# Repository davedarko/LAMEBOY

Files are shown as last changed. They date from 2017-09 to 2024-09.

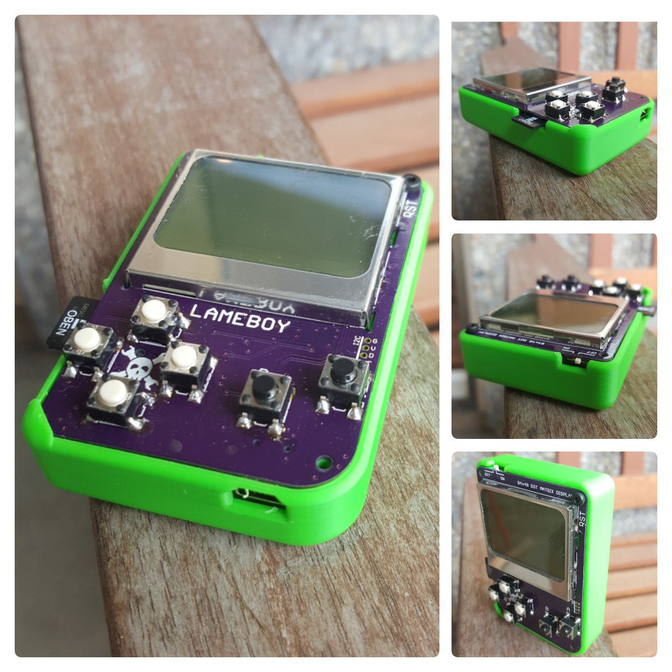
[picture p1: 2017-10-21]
Resources/img/lameboy.jpg

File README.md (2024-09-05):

# LAMEBOY
https://hackaday.io/project/26823-lameboy-another-esp12-handheld

Ever since https://hackaday.io/project/18648-nokia-3310-5110-display-board I've wanted to slap on an ESP module and some buttons to make a nice little portable handheld. Now with some googling and checking out other projects how they get their stuff done and a bit time on hand while on vacation I'm using every spare minute to work on this PCB. There are some minor things I'm not sure about that need testing, but the general concept is clear.

The last version - R 3.2.3 - seems to got lost, it was rebranded to Game Toy and some pinouts were changed to make more sense.

LAMEBOY

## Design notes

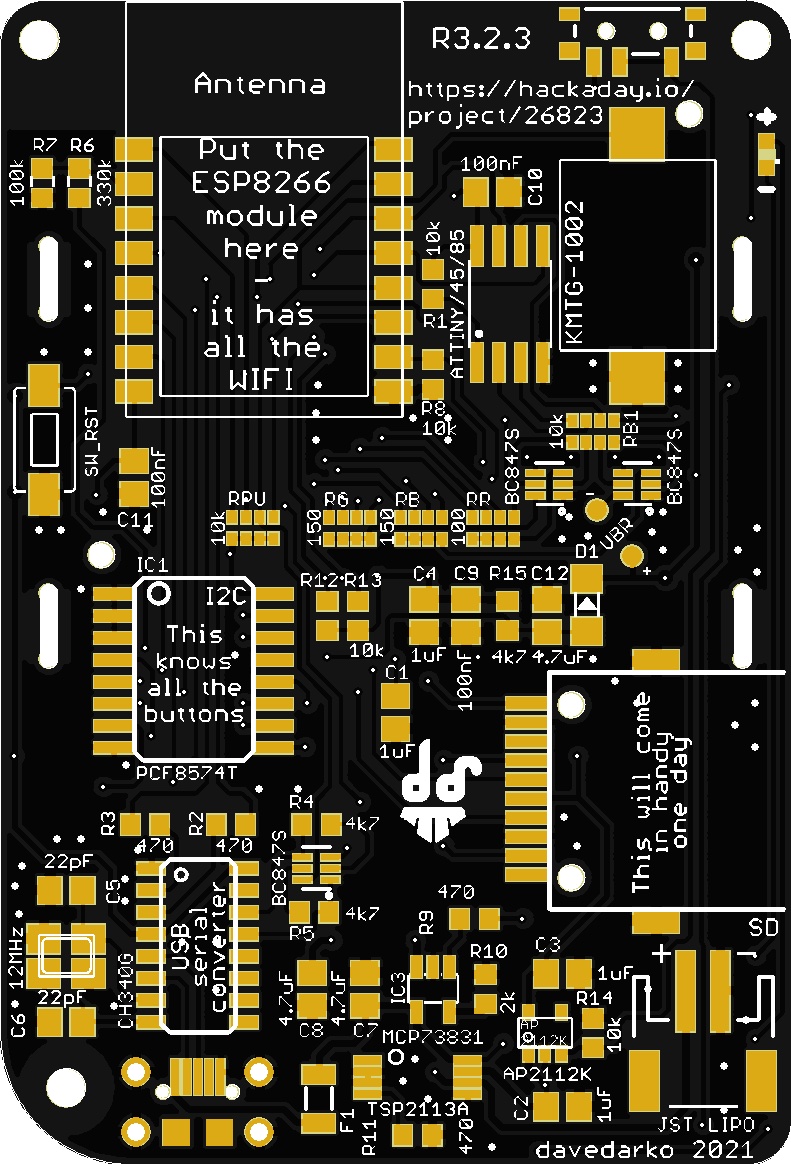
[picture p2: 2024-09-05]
Resources/notBackedUp.jpg

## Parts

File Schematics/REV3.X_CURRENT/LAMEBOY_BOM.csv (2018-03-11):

Qty | Value | Device | Package | Parts | Description | MF | MPN | OC_FARNELL | OC_NEWARK | PROD_ID
1 |  | ESP-12 | ESP-12 | X1
1 |  | JST_2MM_MALE | JST-2-SMD | J1 | Mates to single-cell LiPo batteries. |  |  |  |  | CONN-08352
1 |  | LEDCHARLIE | CHIPLED_0603_CHARLIE | CHARGE | LED
2 |  | SWITCH-MOMENTARY-2-SMD-1101NE | TACTILE-SWITCH-1101NE | SW_C, SW_RST | Various NO switches- pushbuttons, reed, etc
1 | 100 | 4R-N0603-ARC | 0603-ARC | RR | Array Chip Resistor |  |  | unknown | unknown
1 | 100k | R-EU_ONEFITSALL | ONEFITSALL | R7 | RESISTOR, European symbol
3 | 100nF | C-EUONEFITSALL | ONEFITSALL | C9, C10, C11 | CAPACITOR, European symbol
2 | 10k | 4R-N0603-ARC | 0603-ARC | RB1, RPU | Array Chip Resistor |  |  | unknown | unknown
5 | 10k | R-EU_ONEFITSALL | ONEFITSALL | R1, R8, R12, R13, R14 | RESISTOR, European symbol
1 | 12MHz | XTAL-4BIGGER | NX3225_BIGGER | Q1 | Classic 4-pin 3.2 x 2.5mm crystal
2 | 150 | 4R-N0603-ARC | 0603-ARC | RB, RG | Array Chip Resistor |  |  | unknown | unknown
4 | 1uF | C-EUONEFITSALL | ONEFITSALL | C1, C2, C3, C4 | CAPACITOR, European symbol
2 | 22pF | C-EUONEFITSALL | ONEFITSALL | C5, C6 | CAPACITOR, European symbol
1 | 2k | R-EU_ONEFITSALL | ONEFITSALL | R10 | RESISTOR, European symbol
1 | 330k | R-EU_ONEFITSALL | ONEFITSALL | R6 | RESISTOR, European symbol
2 | 4.7uF | C-EUONEFITSALL | ONEFITSALL | C7, C8 | CAPACITOR, European symbol
4 | 470 | R-EU_ONEFITSALL | ONEFITSALL | R2, R3, R9, R11 | RESISTOR, European symbol
2 | 4k7 | R-EU_ONEFITSALL | ONEFITSALL | R4, R5 | RESISTOR, European symbol
1 | AP2112KAP2112K | AP2112KAP2112K | AP2112 | U$9
1 | ATTINY13SO08-WIDE | ATTINY13SO08-WIDE | SO08-EIAJ | U$2 | Atmel 8-pin 1kB flash uC
1 | AVR_SPI_PRG_6 | AVR_SPI_PRG_6 | 2X3_SMD_PAD | JP2 | AVR ISP 6 Pin
3 | BC847S | MMDT3904 | SOT363 | U$3, U$6, U$7 | Dual NPN transistor
1 | CH340GCH340G | CH340GCH340G | SOIC16 | CH340G | USB to TTL RS232 converter
4 | GM1WA55311A | GM1WA55311A | GM1WA55311A | LED1, LED2, LED3, LED4 | Chip LED RGB
1 | I2C_GROVE | I2C_GROVE | I2C_GROVE | U$10
1 | LPH-7366-SLOTS | LPH-7366-SLOTS | LPH-7366-SLOTS | U$1
1 | MCP73831 | MCP73831/OT | SOT23-5L | IC3 | MCP73831/2
1 | PCF8574T | PCF8574T | SO16W | IC1 | I2C-Bus Remote 8-bit I/O expander |  | PCF8574T/3,512 | 1201255 | 70R6870
1 | PTCSMD | PTCSMD | PTC-1206 | F1 | Resettable Fuse PTC |  |  |  |  | RES-11150
1 | PWR | SWITCH-SPDT-SMD-A | SWITCH-SPST-SMD-A | S2 | SPDT Switch
6 | SWITCH-MOMENTARY-2SMD-4 | SWITCH-MOMENTARY-2SMD-4 | TACTILE_SWITCH_TALL | S3, S4, S5, S6, S7, S8 | Various NO switches- pushbuttons, reed, etc |  |  |  |  | SWCH-11966
1 | TPS2113-PW | TPS2113-PW | TEXAS-PW | U$4
1 | USB_MICROB_PLUG-IDK | USB_MICROB_PLUG-IDK | USB-AB-MICRO-SMD_SLOT | JP1 | USB Micro-B connectors
1 | USD-SOCKETMICROSDEBAY | USD-SOCKETMICROSDEBAY | MICRO-SD-SOCKET-EBAY | U1 | microSD Socket

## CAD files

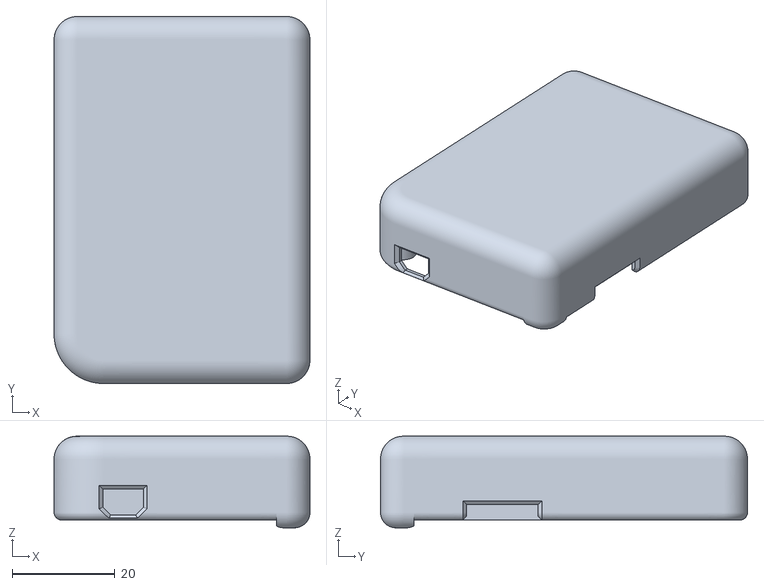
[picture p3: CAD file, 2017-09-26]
CAD/lameboy.stl
49.7 x 71.3 x 17.8

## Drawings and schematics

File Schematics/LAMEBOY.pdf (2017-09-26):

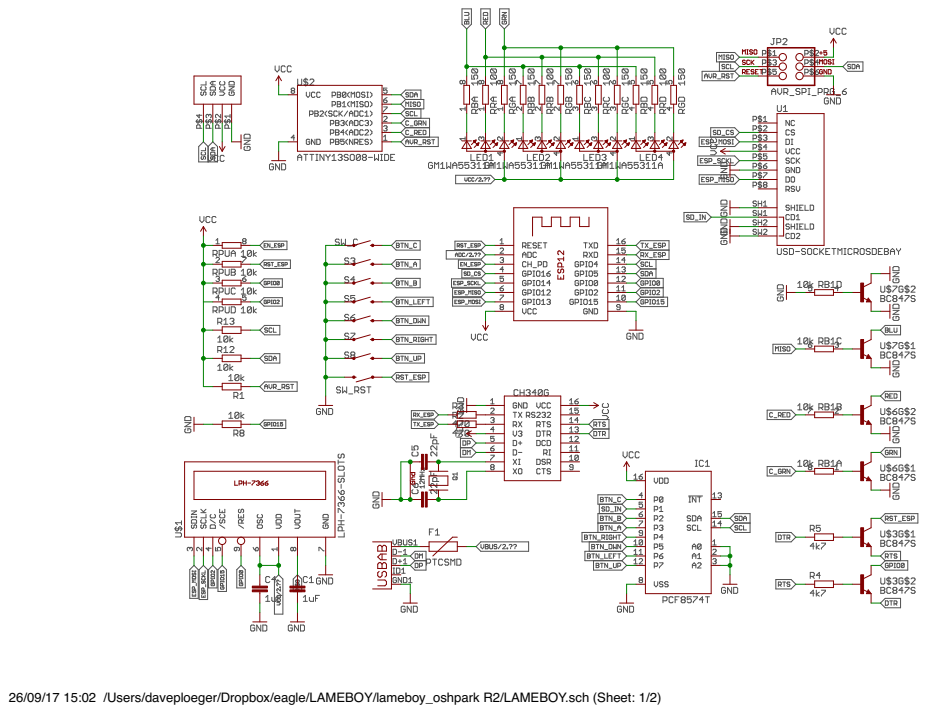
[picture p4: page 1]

26/09/17 15:02 /Users/daveploeger/Dropbox/eagle/LAMEBOY/lameboy_oshpark R2/LAMEBOY.sch (Sheet: 1/2)

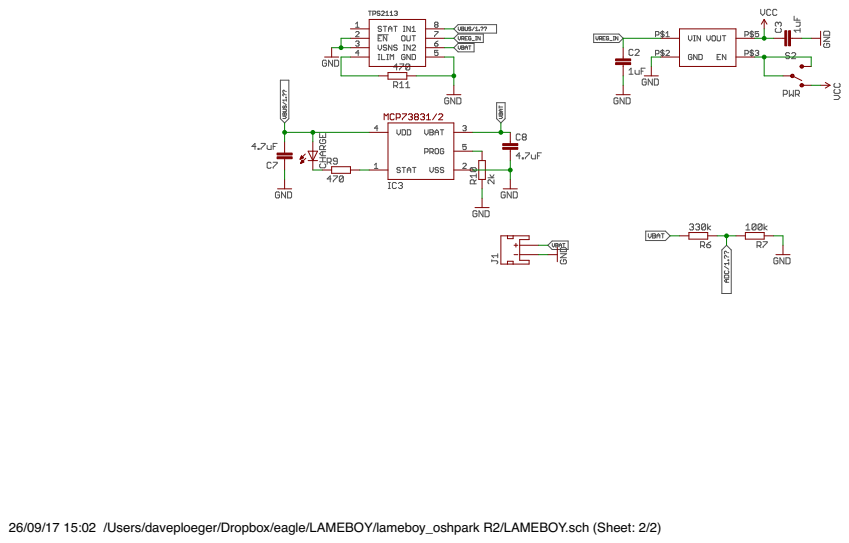
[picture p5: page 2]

26/09/17 15:02 /Users/daveploeger/Dropbox/eagle/LAMEBOY/lameboy_oshpark R2/LAMEBOY.sch (Sheet: 2/2)

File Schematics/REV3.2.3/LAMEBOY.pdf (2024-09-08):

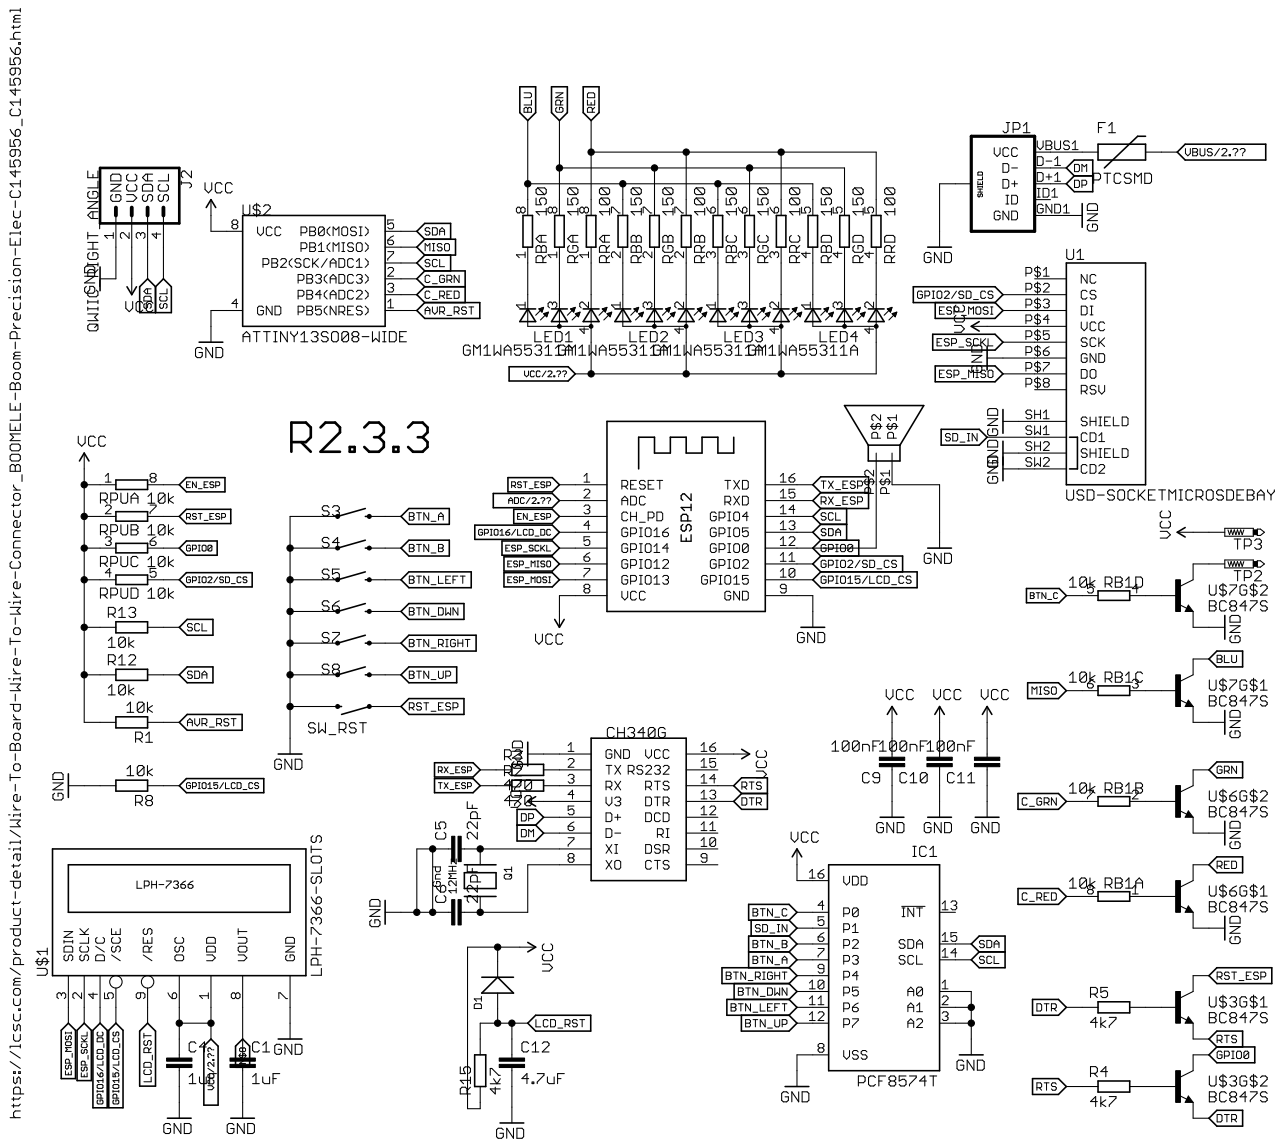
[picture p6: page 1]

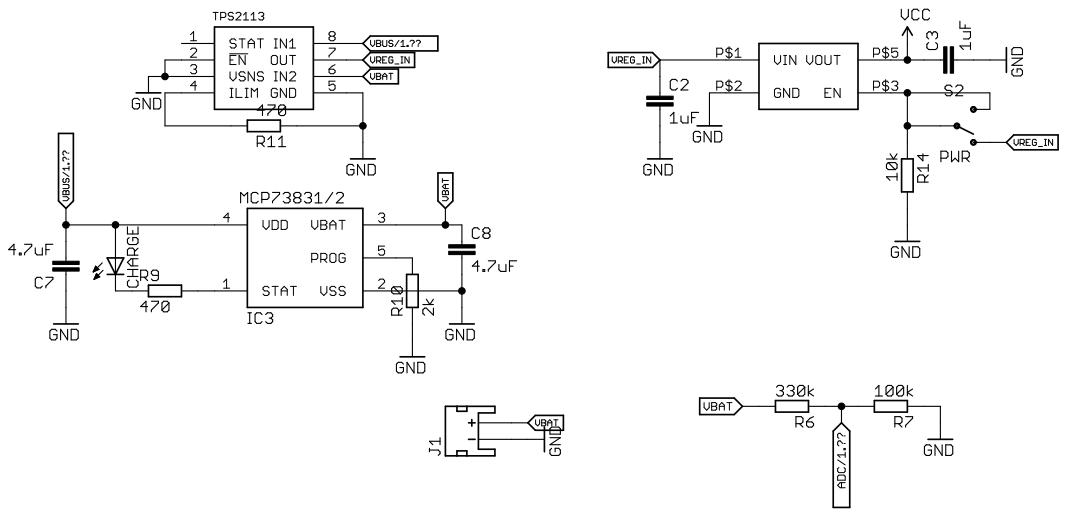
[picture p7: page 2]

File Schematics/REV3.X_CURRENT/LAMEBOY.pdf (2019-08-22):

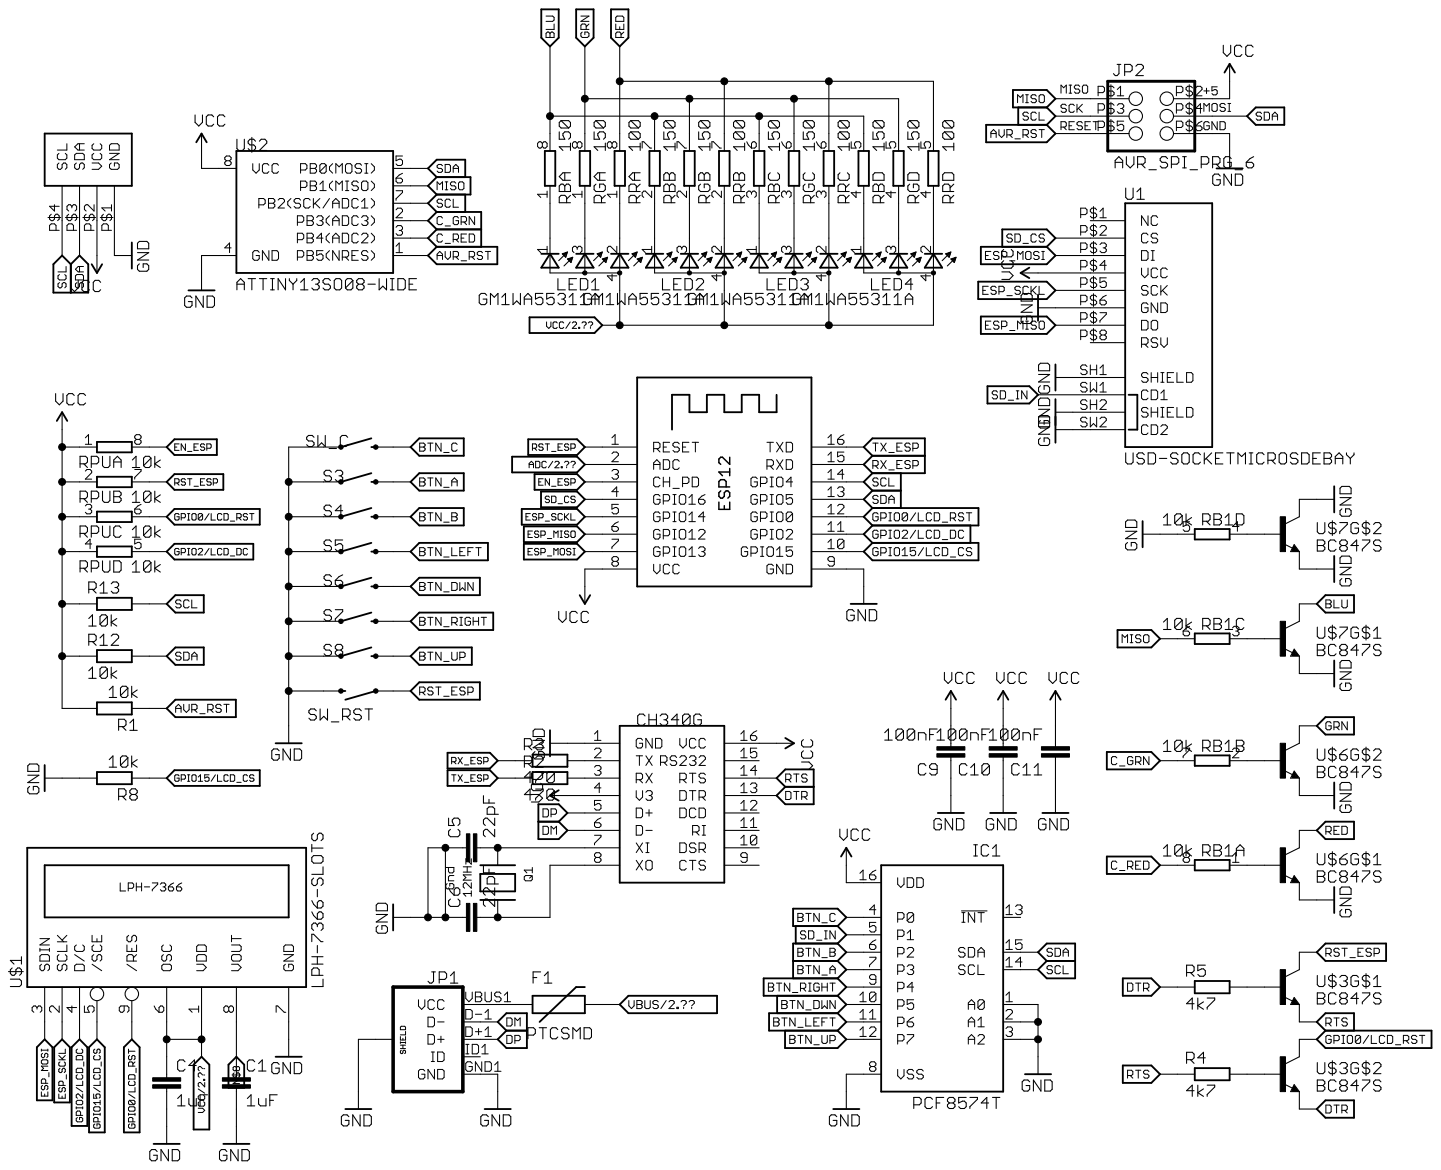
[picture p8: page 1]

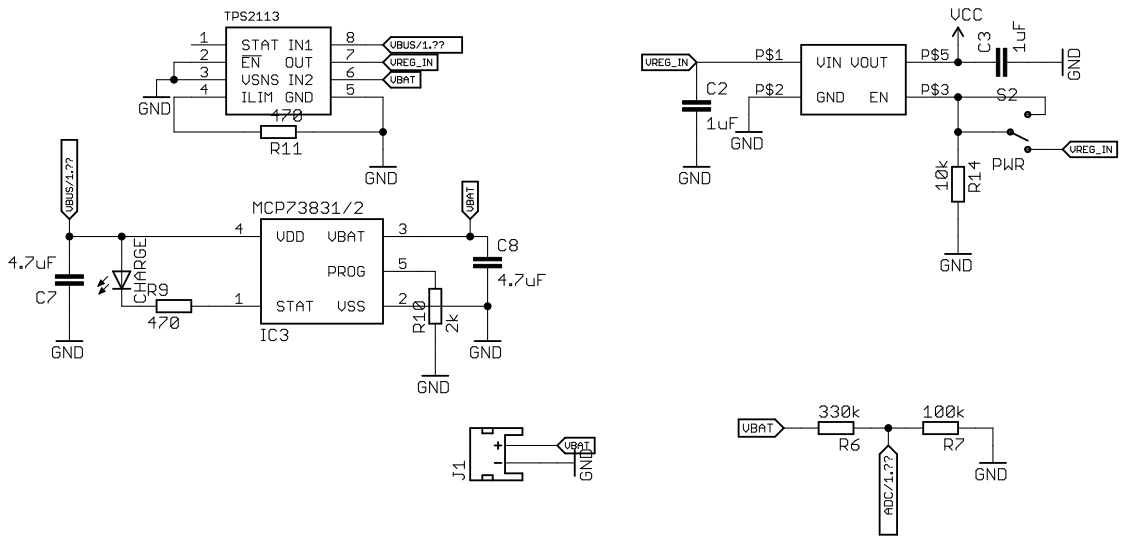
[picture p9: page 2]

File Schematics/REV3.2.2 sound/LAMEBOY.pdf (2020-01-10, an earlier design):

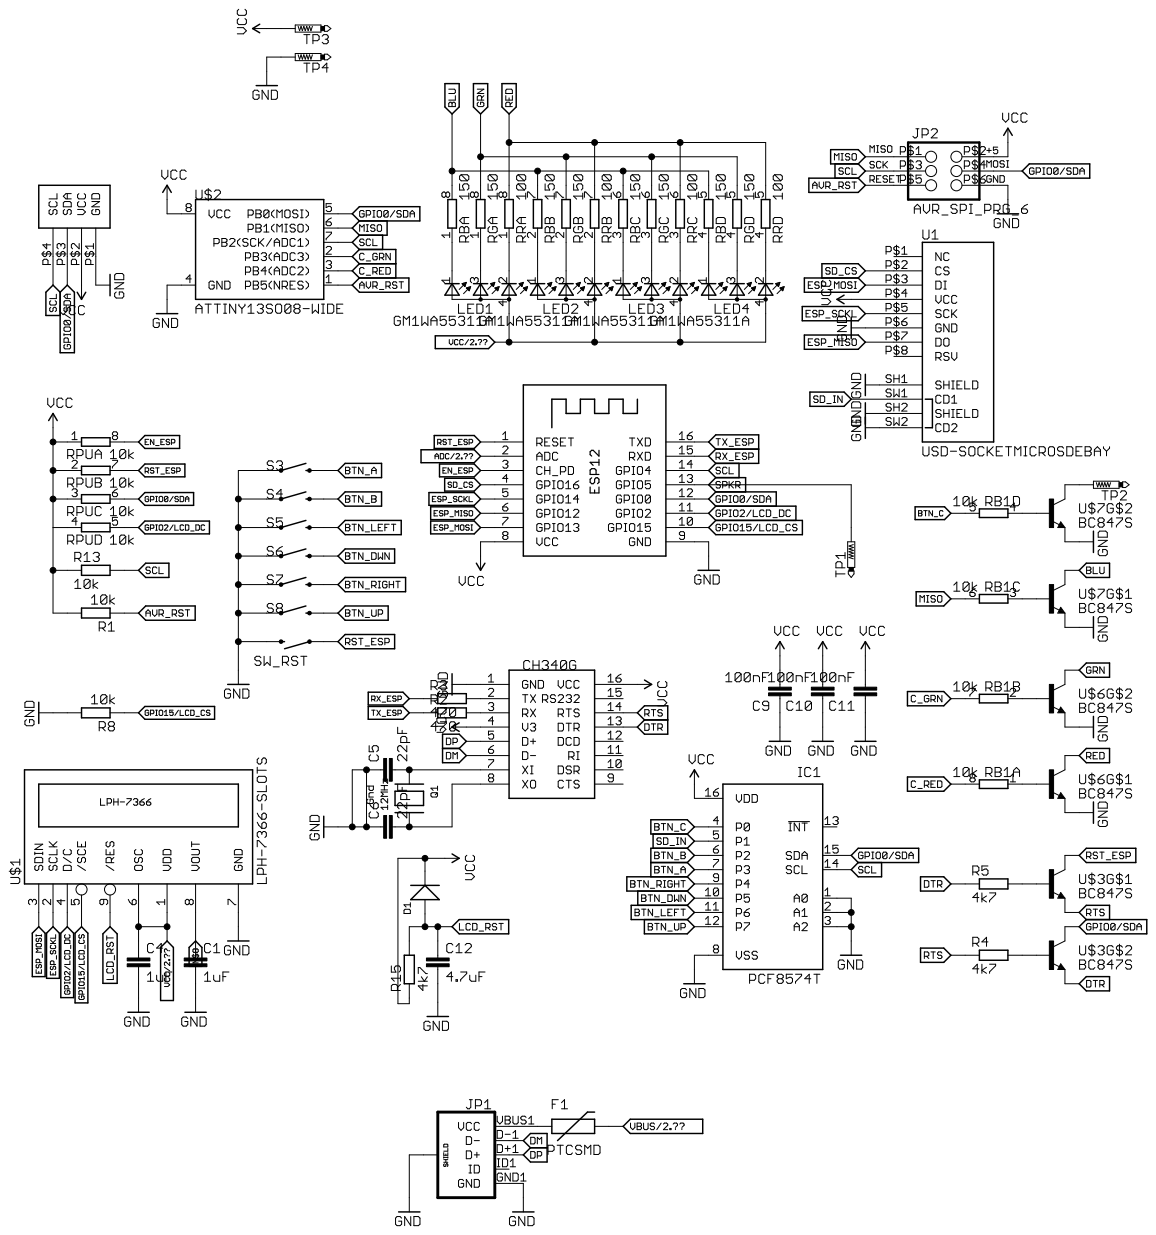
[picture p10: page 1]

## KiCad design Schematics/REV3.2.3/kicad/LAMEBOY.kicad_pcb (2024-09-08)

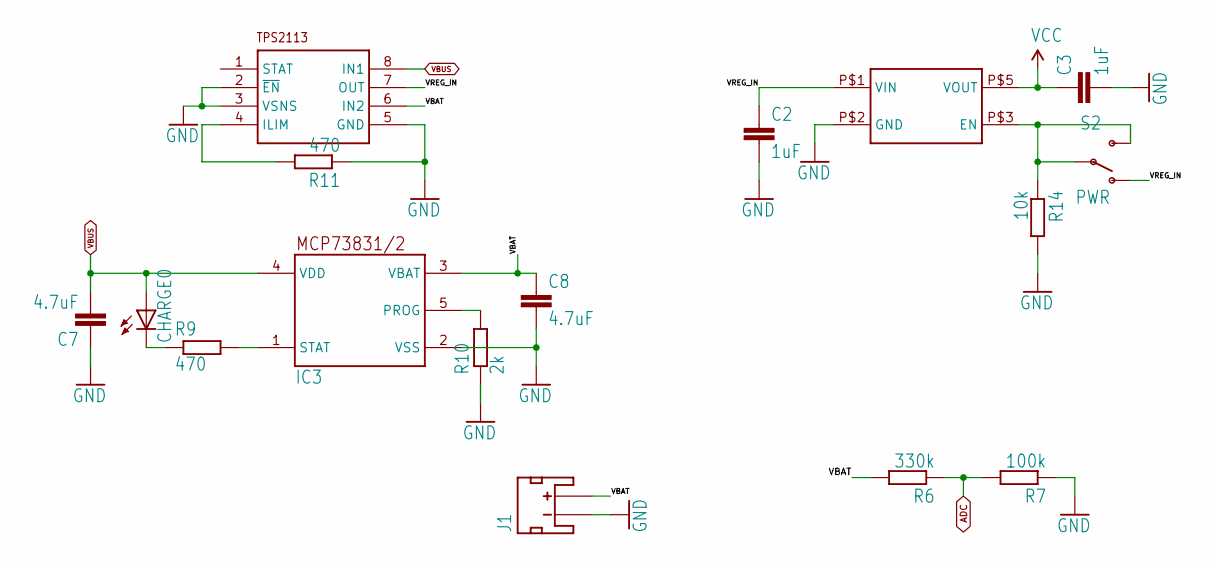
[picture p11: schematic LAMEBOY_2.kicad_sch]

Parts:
C2, C3: 1uF; C0805
C7, C8: 4.7uF; C0805
CHARGE0: LEDCHARLIE; CHIPLED_0603_CHARLIE
IC3: MCP73831; SOT23-5L
J1: JST_2MM_MALE; JST-2-SMD
R6: 330k; R0603
R7: 100k; R0603
R9, R11: 470; R0603
R10: 2k; R0603
R14: 10k; R0603
S2: PWR; SWITCH-SPST-SMD-A
U$4: TPS2113-PW; TEXAS-PW
U$9: AP2112KAP2112K; AP2112

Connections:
ADC: R6.1, R7.2; also elsewhere on the board
GND: C2.2, C3.2, C7.1, C8.2, IC3.2 (VSS), J1.1 (-), R7.1, R10.1, R11.1, R14.2, U$4.2 (~EN), U$4.3 (VSNS), U$4.5 (GND), U$9.P$2 (GND); also elsewhere on the board
unnamed: IC3.1 (STAT), R9.2
unnamed: CHARGE0.C, R9.1
unnamed: R11.2, U$4.4 (ILIM)
unnamed: IC3.5 (PROG), R10.2
VBAT: C8.1, IC3.3 (VBAT), J1.2 (+), R6.2, U$4.6 (IN2)
VBUS: C7.2, CHARGE0.A, IC3.4 (VDD), U$4.8 (IN1); also elsewhere on the board
VCC: C3.1, U$9.P$5 (VOUT); also elsewhere on the board
VREG_EN: R14.1, S2.2, S2.3 (S), U$9.P$3 (EN)
VREG_IN: C2.1, S2.1 (O), U$4.7 (OUT), U$9.P$1 (VIN)

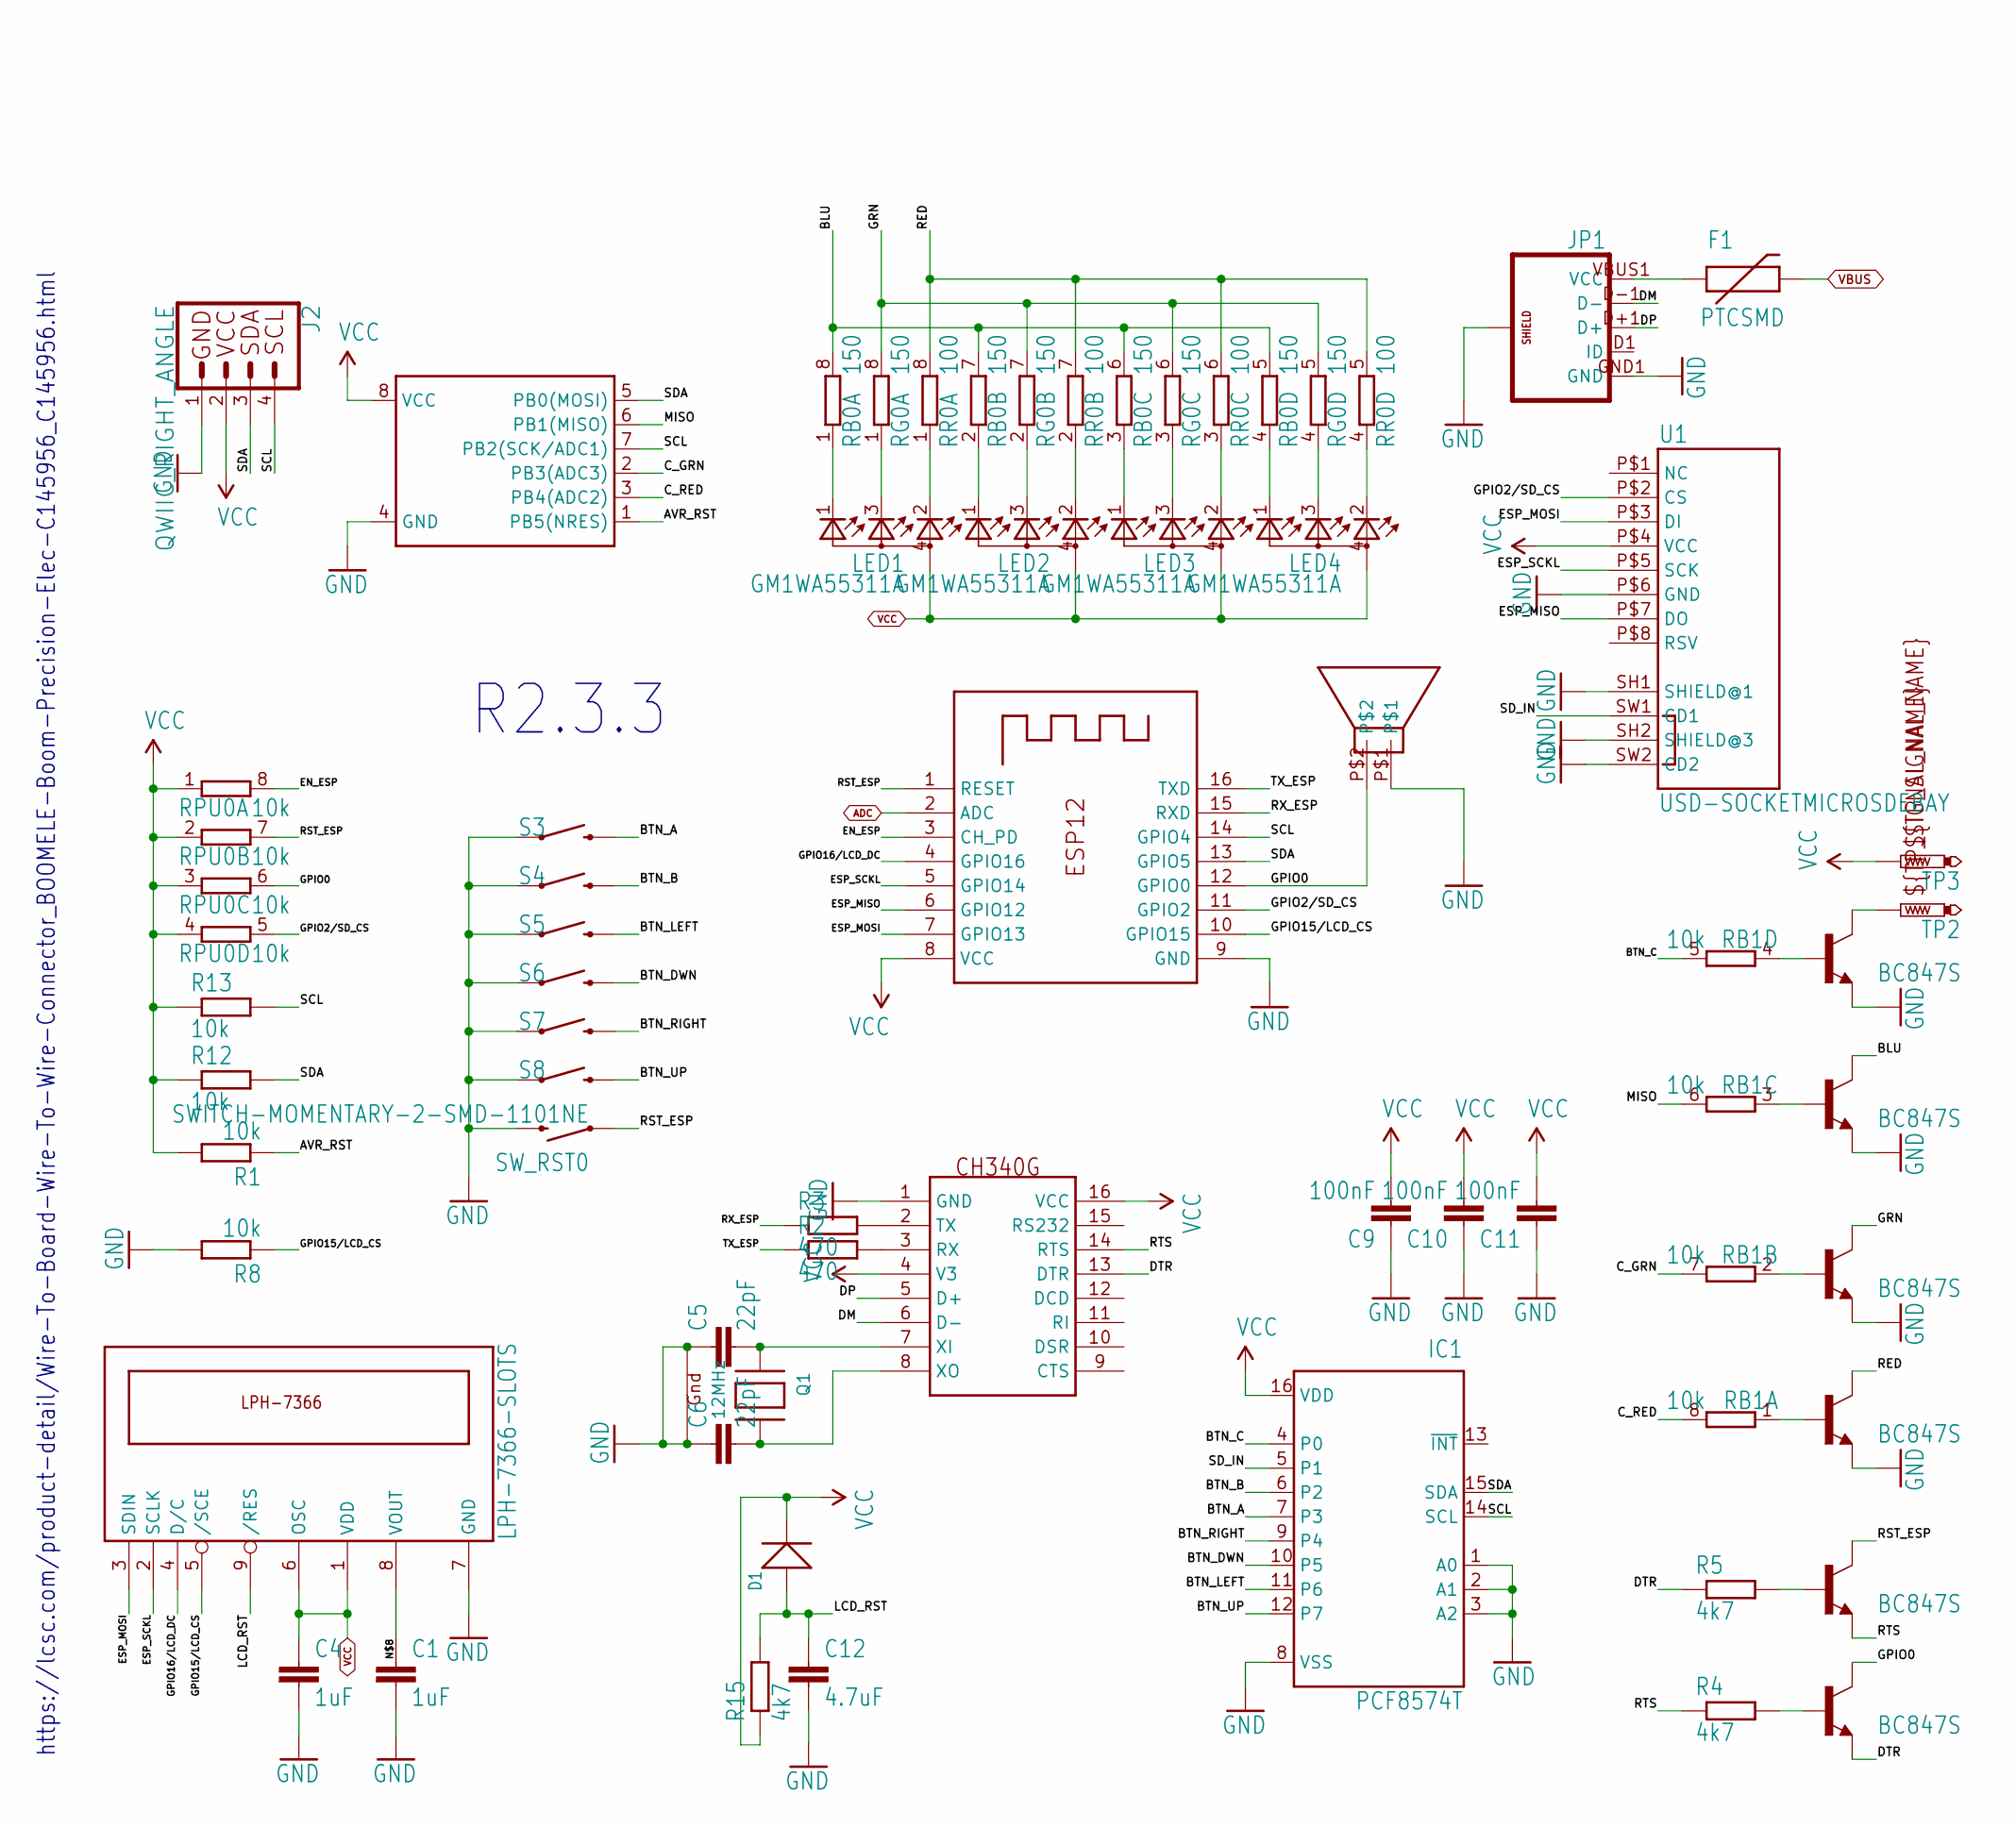
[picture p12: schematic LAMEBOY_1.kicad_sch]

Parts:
C1, C4: 1uF; C0805
C5, C6: 22pF; C0805
C9, C10, C11: 100nF; C0805
C12: 4.7uF; C0805
CH340G0: CH340GCH340G; SOIC16
D1: DIODE'1N4148-SMD'; LL-34
F1: PTCSMD; PTC-1206
IC1: PCF8574T; SO16W
J2: QWIIC_RIGHT_ANGLE; JST04_1MM_RA
JP1: USB_MICROB_PLUG-IDK; USB-AB-MICRO-SMD_SLOT
LED1, LED2, LED3, LED4: GM1WA55311A
Q1: 12MHz; NX3225_BIGGER
R1, R8, R12, R13: 10k; R0603
R2, R3: 470; R0603
R4, R5, R15: 4k7; R0603
RB0: 150; 0603-ARC
RB1: 10k; 0603-ARC
RG0: 150; 0603-ARC
RPU0: 10k; 0603-ARC
RR0: 100; 0603-ARC
S3, S4, S5, S6, S7, S8: SWITCH-MOMENTARY-2SMD-4; TACTILE_SWITCH_TALL
SW_RST0: SWITCH-MOMENTARY-2-SMD-1101NE; TACTILE-SWITCH-1101NE
TP2, TP3: PTR1B1,27; B1,27
U1: USD-SOCKETMICROSDEBAY; MICRO-SD-SOCKET-EBAY
U$1: LPH-7366-SLOTS
U$2: ATTINY13SO08-WIDE; SO08-EIAJ
U$3, U$6, U$7: BC847S; SOT363
U$5: SPEAKERKMTG-1102; KMTG-1102
X1: ESP-12

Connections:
ADC: X1.2 (ADC); also elsewhere on the board
AVR_RST: R1.1, U$2.1 (PB5(NRES))
BLU: RB0.5 (2), RB0.6 (2), RB0.7 (2), RB0.8 (2), U$7.3 (C)
BLUE_LED: LED4.1 (CGREEN), RB0.4 (1)
BTN_A: IC1.7 (P3), S3.B2 (2)
BTN_B: IC1.6 (P2), S4.B2 (2)
BTN_C: IC1.4 (P0), RB1.5 (2)
BTN_DWN: IC1.10 (P5), S6.B2 (2)
BTN_LEFT: IC1.11 (P6), S5.B2 (2)
BTN_RIGHT: IC1.9 (P4), S7.B2 (2)
BTN_UP: IC1.12 (P7), S8.B2 (2)
C_GRN: RB1.7 (2), U$2.2 (PB3(ADC3))
C_RED: RB1.8 (2), U$2.3 (PB4(ADC2))
DM: CH340G0.6 (D-), JP1.D-1 (D-)
DP: CH340G0.5 (D+), JP1.D+1 (D+)
DTR: CH340G0.13 (DTR), R5.1, U$3.1 (E)
EN_ESP: RPU0.8 (2), X1.3 (CH_PD)
ESP_MISO: U1.P$7 (DO), X1.6 (GPIO12)
ESP_MOSI: U1.P$3 (DI), U$1.3 (SDIN), X1.7 (GPIO13)
ESP_SCKL: U1.P$5 (SCK), U$1.2 (SCLK), X1.5 (GPIO14)
GND: C1.2, C4.2, C5.1, C6.1, C9.1, C10.1, C11.1, C12.2, CH340G0.1 (GND), IC1.1 (A0), IC1.2 (A1), IC1.3 (A2), IC1.8 (VSS), J2.1, JP1.GND1 (GND), JP1.P$1 (SHIELD), JP1.P$2 (SHIELD), JP1.P$3 (SHIELD), JP1.P$4 (SHIELD), Q1.2 (G2), Q1.4 (G1), R8.2, S3.A2 (1), S4.A2 (1), S5.A2 (1), S6.A2 (1), S7.A2 (1), S8.A2 (1), SW_RST0.P$2 (2), U1.P$6 (GND), U1.SH1 (SHIELD@1), U1.SH2 (SHIELD@3), U1.SW2 (CD2), U$1.7 (GND), U$2.4 (GND), U$5.P$1, U$6.1 (E), U$6.4 (E), U$7.1 (E), U$7.4 (E), X1.9 (GND); also elsewhere on the board
GPIO0: RPU0.6 (2), U$3.6 (C), U$5.P$2, X1.12 (GPIO0)
GPIO2/SD_CS: RPU0.5 (2), U1.P$2 (CS), X1.11 (GPIO2)
GPIO15/LCD_CS: R8.1, U$1.5 (/SCE), X1.10 (GPIO15)
GPIO16/LCD_DC: U$1.4 (D/C), X1.4 (GPIO16)
GREEN_LED: LED4.3 (CBLUE), RG0.4 (1)
GRN: RG0.5 (2), RG0.6 (2), RG0.7 (2), RG0.8 (2), U$6.6 (C)
L2_R: LED1.3 (CBLUE), RG0.1
L3_B: LED1.1 (CGREEN), RB0.1
L4_G: LED1.2 (CRED), RR0.1
LCD_RST: C12.1, D1.A (+), R15.2, U$1.9 (/RES)
MISO: RB1.6 (2), U$2.6 (PB1(MISO))
unnamed: LED3.1 (CGREEN), RB0.3 (1)
unnamed: LED3.3 (CBLUE), RG0.3 (1)
unnamed: LED3.2 (CRED), RR0.3 (1)
unnamed: LED2.1 (CGREEN), RB0.2 (1)
unnamed: C1.1, U$1.8 (VOUT)
unnamed: LED2.3 (CBLUE), RG0.2 (1)
unnamed: LED2.2 (CRED), RR0.2 (1)
unnamed: RB1.1, U$6.5 (B)
unnamed: RB1.2 (1), U$6.2 (B)
unnamed: TP2.TP, U$7.6 (C)
unnamed: C5.2, CH340G0.7 (XI), Q1.1 (X1)
unnamed: RB1.3 (1), U$7.5 (B)
unnamed: RB1.4 (1), U$7.2 (B)
unnamed: C6.2, CH340G0.8 (XO), Q1.3 (X2)
unnamed: R5.2, U$3.5 (B)
unnamed: CH340G0.3 (RX), R2.2
unnamed: CH340G0.2 (TX), R3.2
unnamed: R4.2, U$3.2 (B)
RED: RR0.5 (2), RR0.6 (2), RR0.7 (2), RR0.8 (2), U$6.3 (C)
RED_LED: LED4.2 (CRED), RR0.4 (1)
RST_ESP: RPU0.7 (2), SW_RST0.P$1 (1), U$3.3 (C), X1.1 (RESET)
RTS: CH340G0.14 (RTS), R4.1, U$3.4 (E)
RX_ESP: R3.1, X1.15 (RXD)
SCL: IC1.14 (SCL), J2.4, R13.2, U$2.7 (PB2(SCK/ADC1)), X1.14 (GPIO4)
SDA: IC1.15 (SDA), J2.3, R12.2, U$2.5 (PB0(MOSI)), X1.13 (GPIO5)
SD_IN: IC1.5 (P1), U1.SW1 (CD1)
TX_ESP: R2.1, X1.16 (TXD)
VBUS: F1.2; also elsewhere on the board
VCC: C4.1, C9.2, C10.2, C11.2, CH340G0.4 (V3), CH340G0.16 (VCC), D1.C (-), IC1.16 (VDD), J2.2, LED1.4 (A), LED2.4 (A), LED3.4 (A), LED4.4 (A), R1.2, R12.1, R13.1, R15.1, RPU0.1, RPU0.2 (1), RPU0.3 (1), RPU0.4 (1), TP3.TP, U1.P$4 (VCC), U$1.1 (VDD), U$1.6 (OSC), U$2.8 (VCC), X1.8 (VCC); also elsewhere on the board
VUSB: F1.1, JP1.VBUS1 (VCC)

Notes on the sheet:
R2.3.3
https://lcsc.com/product-detail/Wire-To-Board-Wire-To-Wire-Connector_BOOMELE-Boom-Precision-Elec-C145956_C145956.html

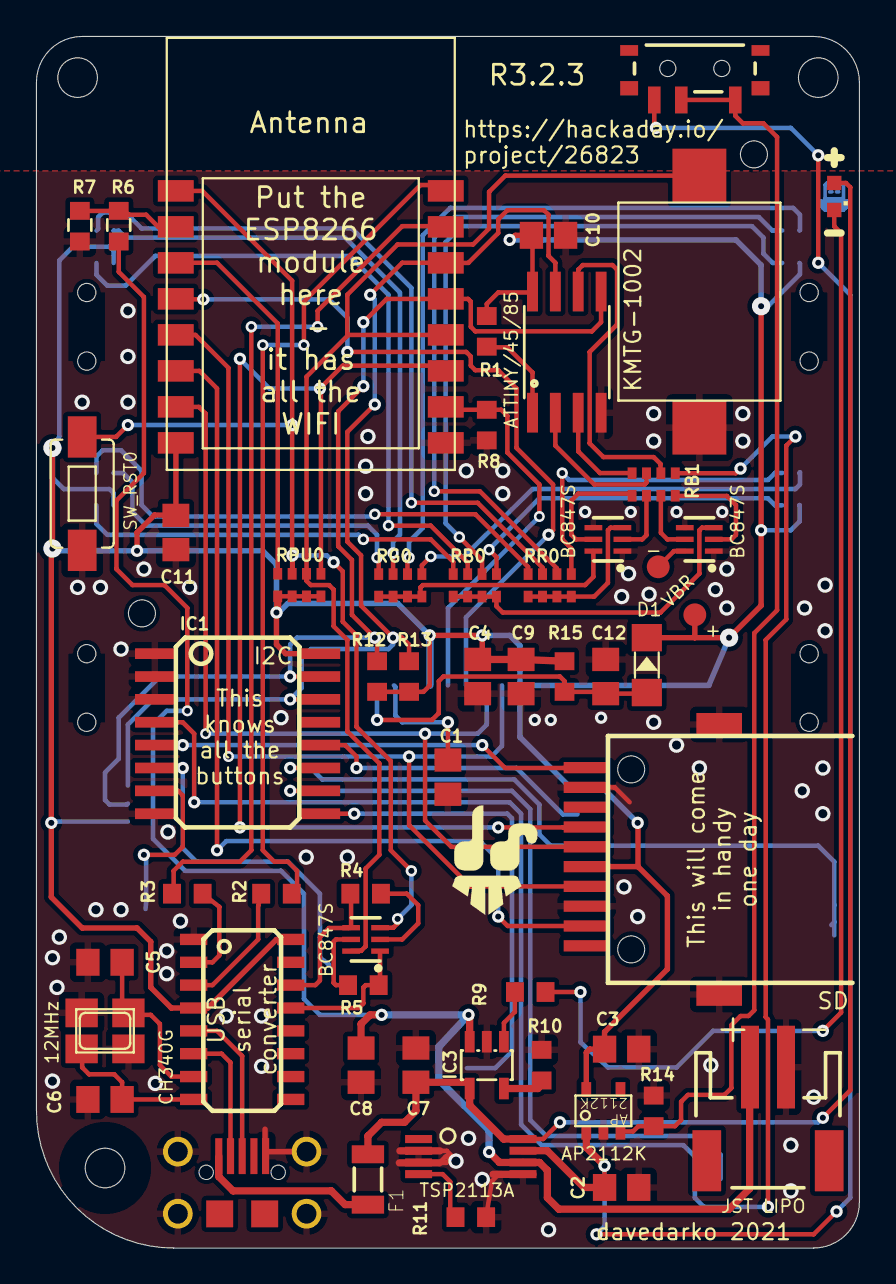
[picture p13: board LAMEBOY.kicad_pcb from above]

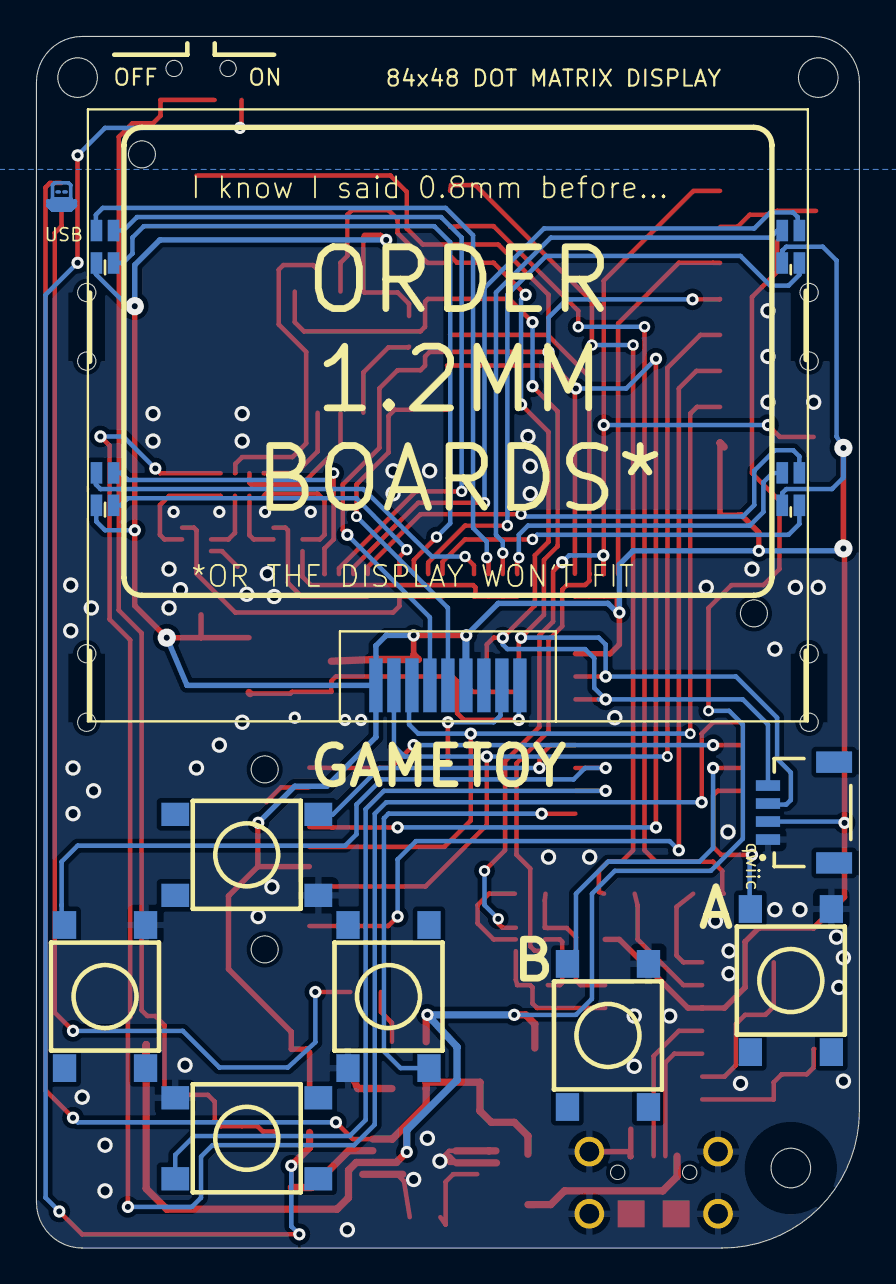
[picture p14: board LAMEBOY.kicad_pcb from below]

Board: 2 copper layers, 45.7 x 67.3 mm, 71 parts (13 on the bottom side), 69 nets.

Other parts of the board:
@HOLE0, @HOLE1, @HOLE2: (no value)
U$11: DAVEDARKO2_LOGO
U$13: DAVEDARKO_GOLD

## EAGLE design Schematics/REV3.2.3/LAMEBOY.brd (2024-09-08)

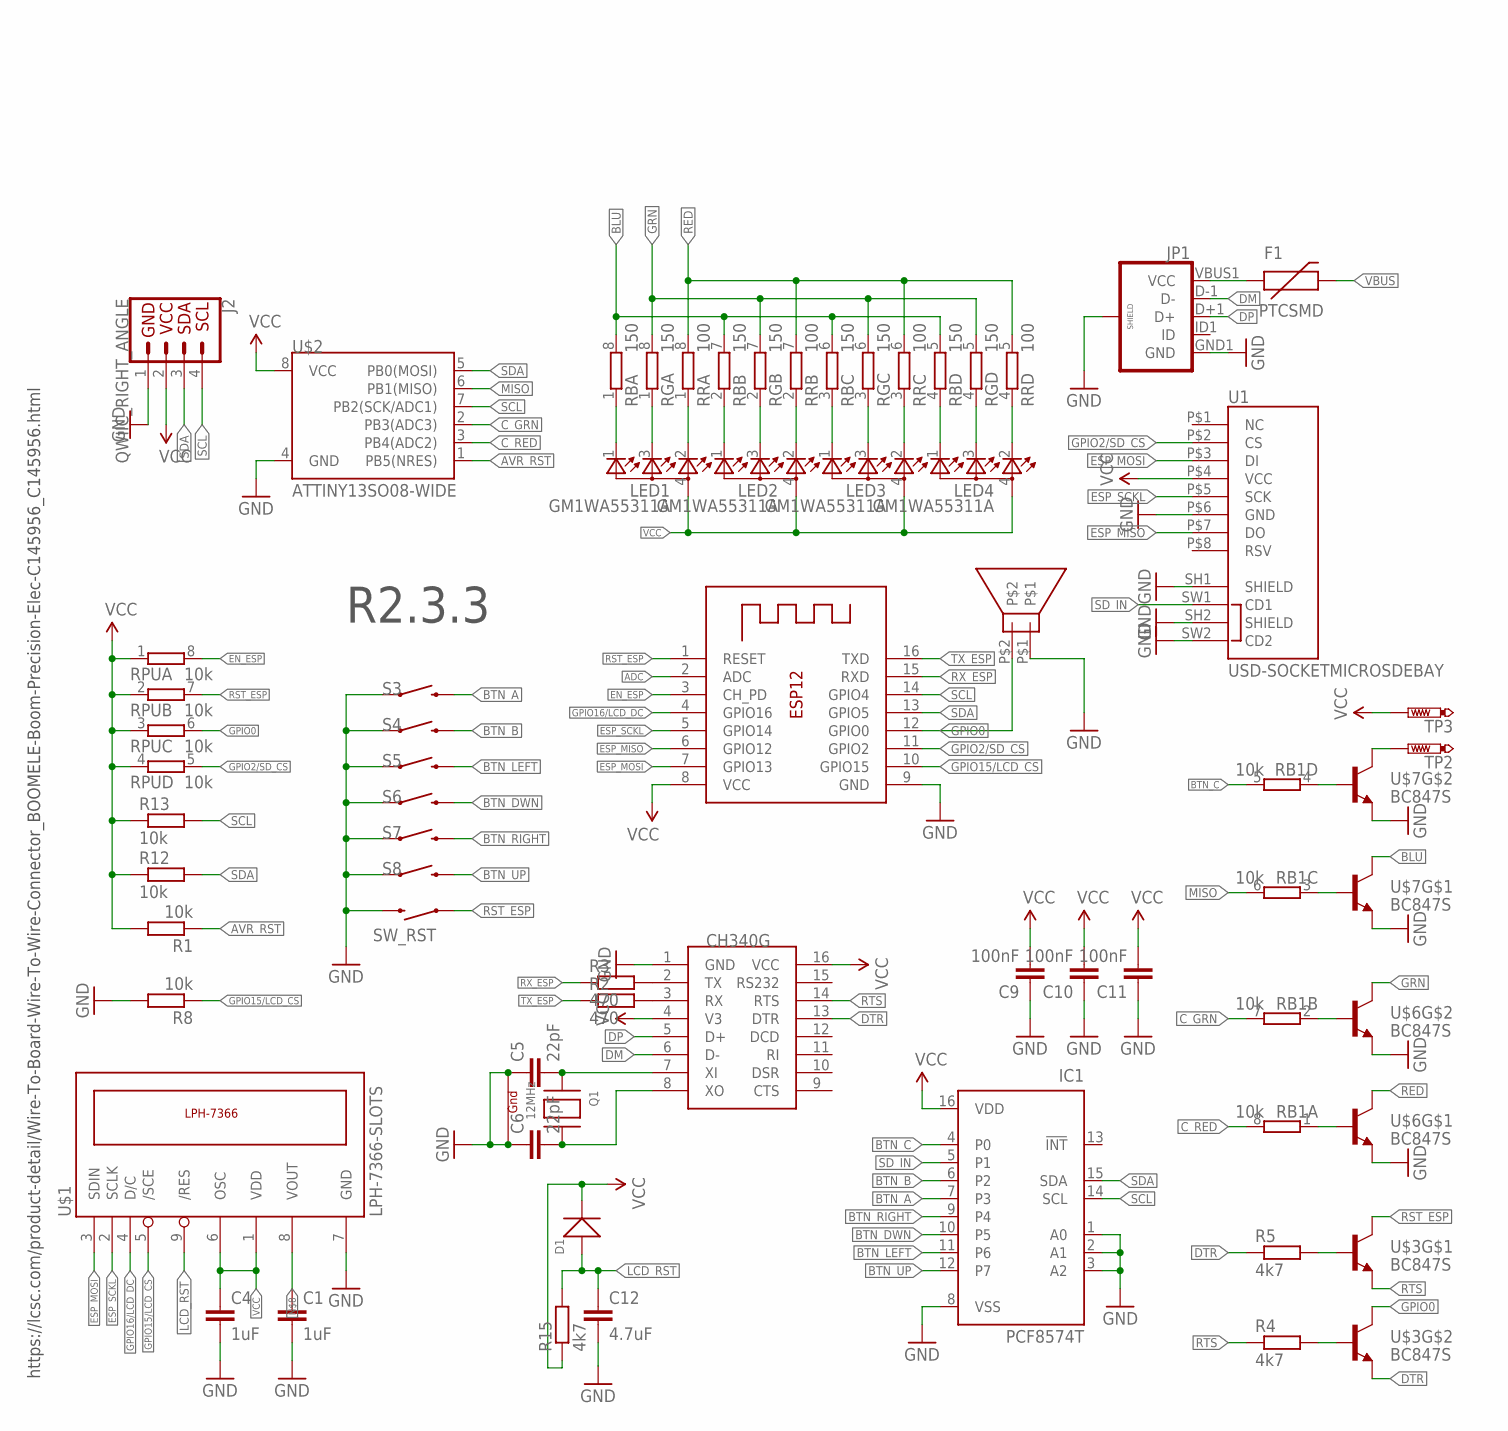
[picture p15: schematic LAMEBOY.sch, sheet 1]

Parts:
C1, C4: 1uF; C0805
C5, C6: 22pF; C0805
C9, C10, C11: 100nF; C0805
C12: 4.7uF; C0805
CH340G: CH340GCH340G; SOIC16
D1: DIODE'1N4148-SMD'; LL-34
F1: PTCSMD; PTC-1206
IC1: PCF8574T; SO16W
J2: QWIIC_RIGHT_ANGLE; JST04_1MM_RA
JP1: USB_MICROB_PLUG-IDK; USB-AB-MICRO-SMD_SLOT
LED1, LED2, LED3, LED4: GM1WA55311A
Q1: 12MHz; NX3225_BIGGER
R1, R8, R12, R13: 10k; R0603
R2, R3: 470; R0603
R4, R5, R15: 4k7; R0603
RB: 150; 0603-ARC
RB1: 10k; 0603-ARC
RG: 150; 0603-ARC
RPU: 10k; 0603-ARC
RR: 100; 0603-ARC
S3, S4, S5, S6, S7, S8: SWITCH-MOMENTARY-2SMD-4; TACTILE_SWITCH_TALL
SW_RST: SWITCH-MOMENTARY-2-SMD-1101NE; TACTILE-SWITCH-1101NE
TP2, TP3: PTR1B1,27; B1,27
U1: USD-SOCKETMICROSDEBAY; MICRO-SD-SOCKET-EBAY
U$1: LPH-7366-SLOTS
U$2: ATTINY13SO08-WIDE; SO08-EIAJ
U$3, U$6, U$7: BC847S; SOT363
U$5: SPEAKERKMTG-1102; KMTG-1102
X1: ESP-12

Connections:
ADC: X1.2 (ADC); also elsewhere on the board
AVR_RST: R1.1, U$2.1 (PB5(NRES))
BLU: RB.5 (2), RB.6 (2), RB.7 (2), RB.8 (2), U$7.3 (C)
BLUE_LED: LED4.1 (CGREEN), RB.4 (1)
BTN_A: IC1.7 (P3), S3.B2 (2)
BTN_B: IC1.6 (P2), S4.B2 (2)
BTN_C: IC1.4 (P0), RB1.5 (2)
BTN_DWN: IC1.10 (P5), S6.B2 (2)
BTN_LEFT: IC1.11 (P6), S5.B2 (2)
BTN_RIGHT: IC1.9 (P4), S7.B2 (2)
BTN_UP: IC1.12 (P7), S8.B2 (2)
C_GRN: RB1.7 (2), U$2.2 (PB3(ADC3))
C_RED: RB1.8 (2), U$2.3 (PB4(ADC2))
DM: CH340G.6 (D-), JP1.D-1 (D-)
DP: CH340G.5 (D+), JP1.D+1 (D+)
DTR: CH340G.13 (DTR), R5.1, U$3.1 (E)
EN_ESP: RPU.8 (2), X1.3 (CH_PD)
ESP_MISO: U1.P$7 (DO), X1.6 (GPIO12)
ESP_MOSI: U1.P$3 (DI), U$1.3 (SDIN), X1.7 (GPIO13)
ESP_SCKL: U1.P$5 (SCK), U$1.2 (SCLK), X1.5 (GPIO14)
GND: C1.2, C4.2, C5.1, C6.1, C9.1, C10.1, C11.1, C12.2, CH340G.1 (GND), IC1.1 (A0), IC1.2 (A1), IC1.3 (A2), IC1.8 (VSS), J2.1, JP1.GND1 (GND), JP1.P$1 (SHIELD), JP1.P$2 (SHIELD), JP1.P$3 (SHIELD), JP1.P$4 (SHIELD), Q1.2 (G2), Q1.4 (G1), R8.2, S3.A2 (1), S4.A2 (1), S5.A2 (1), S6.A2 (1), S7.A2 (1), S8.A2 (1), SW_RST.P$2 (2), U1.P$6 (GND), U1.SH1 (SHIELD), U1.SH2 (SHIELD), U1.SW2 (CD2), U$1.7 (GND), U$2.4 (GND), U$5.P$1, U$6.1 (E), U$6.4 (E), U$7.1 (E), U$7.4 (E), X1.9 (GND); also elsewhere on the board
GPIO0: RPU.6 (2), U$3.6 (C), U$5.P$2, X1.12 (GPIO0)
GPIO2/SD_CS: RPU.5 (2), U1.P$2 (CS), X1.11 (GPIO2)
GPIO15/LCD_CS: R8.1, U$1.5 (/SCE), X1.10 (GPIO15)
GPIO16/LCD_DC: U$1.4 (D/C), X1.4 (GPIO16)
GREEN_LED: LED4.3 (CBLUE), RG.4 (1)
GRN: RG.5 (2), RG.6 (2), RG.7 (2), RG.8 (2), U$6.6 (C)
L2_R: LED1.3 (CBLUE), RG.1
L3_B: LED1.1 (CGREEN), RB.1
L4_G: LED1.2 (CRED), RR.1
LCD_RST: C12.1, D1.A (+), R15.2, U$1.9 (/RES)
MISO: RB1.6 (2), U$2.6 (PB1(MISO))
unnamed: LED3.1 (CGREEN), RB.3 (1)
unnamed: LED3.3 (CBLUE), RG.3 (1)
unnamed: LED3.2 (CRED), RR.3 (1)
unnamed: LED2.1 (CGREEN), RB.2 (1)
unnamed: C1.1, U$1.8 (VOUT)
unnamed: LED2.3 (CBLUE), RG.2 (1)
unnamed: LED2.2 (CRED), RR.2 (1)
unnamed: RB1.1, U$6.5 (B)
unnamed: RB1.2 (1), U$6.2 (B)
unnamed: TP2.TP, U$7.6 (C)
unnamed: C5.2, CH340G.7 (XI), Q1.1 (X1)
unnamed: RB1.3 (1), U$7.5 (B)
unnamed: RB1.4 (1), U$7.2 (B)
unnamed: C6.2, CH340G.8 (XO), Q1.3 (X2)
unnamed: R5.2, U$3.5 (B)
unnamed: CH340G.3 (RX), R2.2
unnamed: CH340G.2 (TX), R3.2
unnamed: R4.2, U$3.2 (B)
RED: RR.5 (2), RR.6 (2), RR.7 (2), RR.8 (2), U$6.3 (C)
RED_LED: LED4.2 (CRED), RR.4 (1)
RST_ESP: RPU.7 (2), SW_RST.P$1 (1), U$3.3 (C), X1.1 (RESET)
RTS: CH340G.14 (RTS), R4.1, U$3.4 (E)
RX_ESP: R3.1, X1.15 (RXD)
SCL: IC1.14 (SCL), J2.4, R13.2, U$2.7 (PB2(SCK/ADC1)), X1.14 (GPIO4)
SDA: IC1.15 (SDA), J2.3, R12.2, U$2.5 (PB0(MOSI)), X1.13 (GPIO5)
SD_IN: IC1.5 (P1), U1.SW1 (CD1)
TX_ESP: R2.1, X1.16 (TXD)
VBUS: F1.2; also elsewhere on the board
VCC: C4.1, C9.2, C10.2, C11.2, CH340G.4 (V3), CH340G.16 (VCC), D1.C (-), IC1.16 (VDD), J2.2, LED1.4 (A), LED2.4 (A), LED3.4 (A), LED4.4 (A), R1.2, R12.1, R13.1, R15.1, RPU.1, RPU.2 (1), RPU.3 (1), RPU.4 (1), TP3.TP, U1.P$4 (VCC), U$1.1 (VDD), U$1.6 (OSC), U$2.8 (VCC), X1.8 (VCC); also elsewhere on the board
VUSB: F1.1, JP1.VBUS1 (VCC)

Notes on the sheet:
R2.3.3
https://lcsc.com/product-detail/Wire-To-Board-Wire-To-Wire-Connector_BOOMELE-Boom-Precision-Elec-C145956_C145956.html

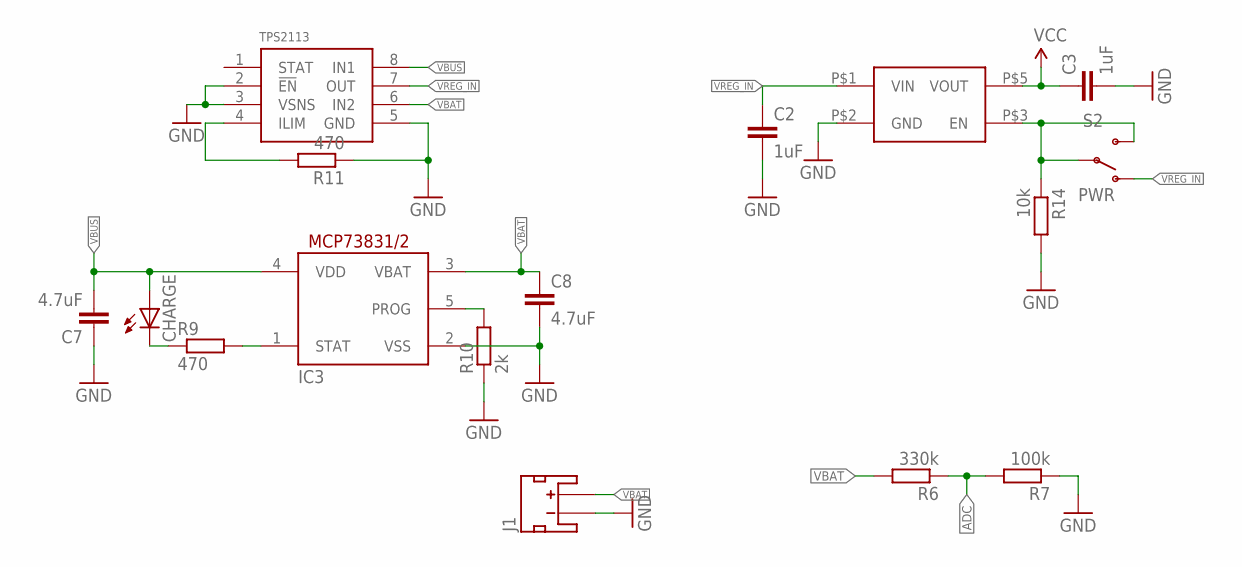
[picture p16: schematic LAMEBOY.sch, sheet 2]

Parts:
C2, C3: 1uF; C0805
C7, C8: 4.7uF; C0805
CHARGE: LEDCHARLIE; CHIPLED_0603_CHARLIE
IC3: MCP73831; SOT23-5L
J1: JST_2MM_MALE; JST-2-SMD
R6: 330k; R0603
R7: 100k; R0603
R9, R11: 470; R0603
R10: 2k; R0603
R14: 10k; R0603
S2: PWR; SWITCH-SPST-SMD-A
U$4: TPS2113-PW; TEXAS-PW
U$9: AP2112KAP2112K; AP2112

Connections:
ADC: R6.1, R7.2; also elsewhere on the board
GND: C2.2, C3.2, C7.1, C8.2, IC3.2 (VSS), J1.1 (-), R7.1, R10.1, R11.1, R14.2, U$4.2 (!EN), U$4.3 (VSNS), U$4.5 (GND), U$9.P$2 (GND); also elsewhere on the board
unnamed: IC3.1 (STAT), R9.2
unnamed: CHARGE.C, R9.1
unnamed: R11.2, U$4.4 (ILIM)
unnamed: IC3.5 (PROG), R10.2
VBAT: C8.1, IC3.3 (VBAT), J1.2 (+), R6.2, U$4.6 (IN2)
VBUS: C7.2, CHARGE.A, IC3.4 (VDD), U$4.8 (IN1); also elsewhere on the board
VCC: C3.1, U$9.P$5 (VOUT); also elsewhere on the board
VREG_EN: R14.1, S2.2, S2.3 (S), U$9.P$3 (EN)
VREG_IN: C2.1, S2.1 (O), U$4.7 (OUT), U$9.P$1 (VIN)

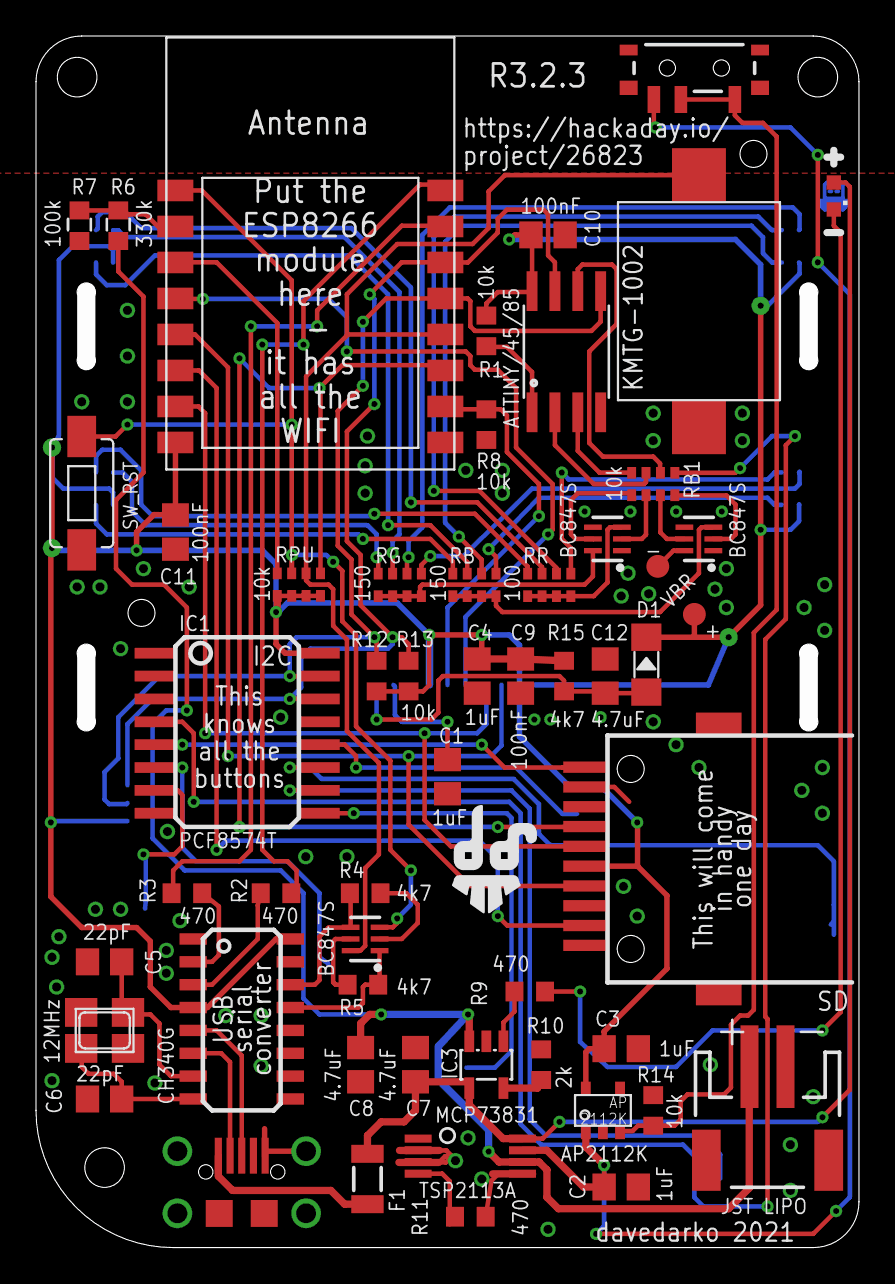
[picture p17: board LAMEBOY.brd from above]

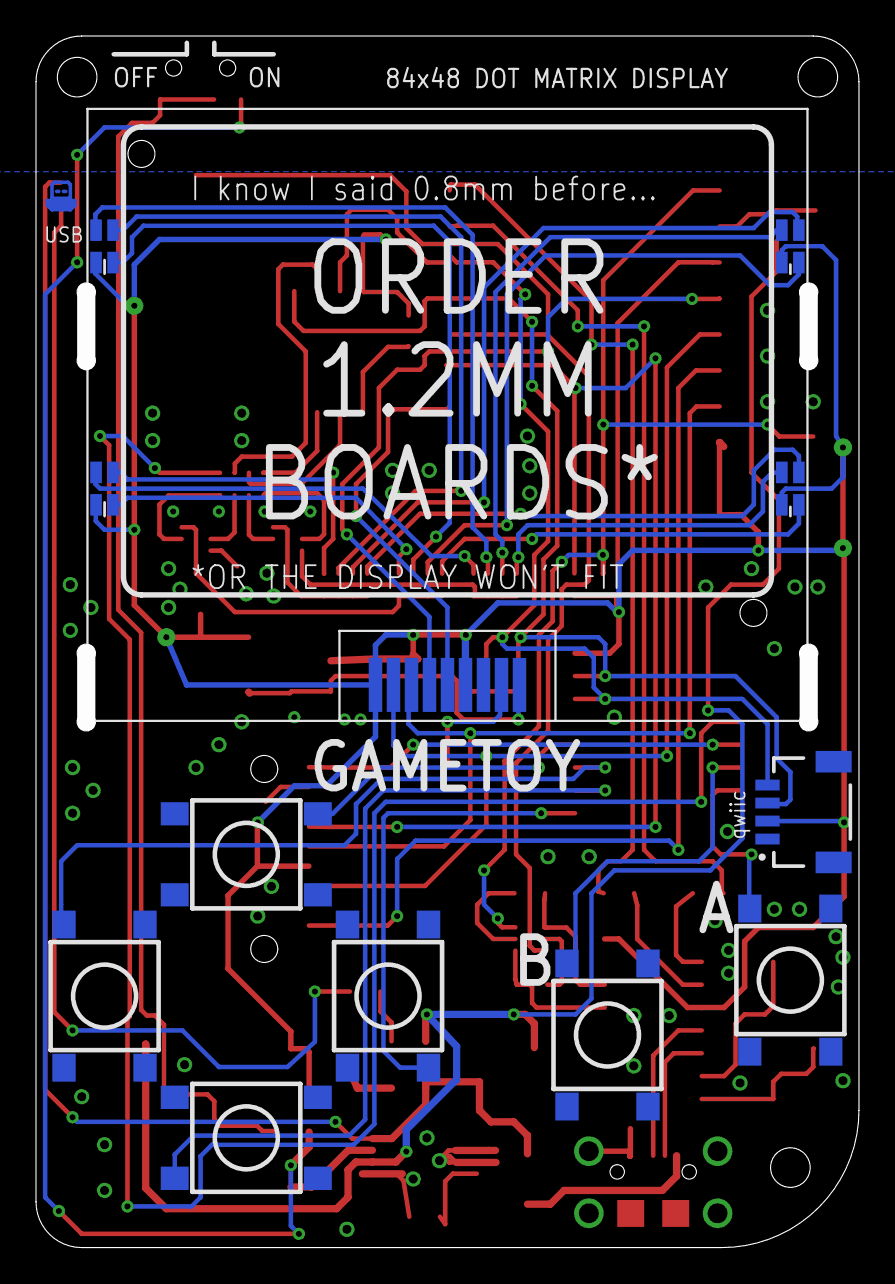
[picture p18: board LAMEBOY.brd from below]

Board: 2 copper layers, 45.7 x 67.3 mm, 68 parts (13 on the bottom side), 69 nets.

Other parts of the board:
U$11: DAVEDARKO2_LOGO
U$13: DAVEDARKO_GOLD

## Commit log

2017-10-04 bigger better resistor and crystal footprint
    [LAMEBOY.brd, LAMEBOY.sch]
2017-10-14 no idea. there's stuff changed so I push.
    [LAMEBOY.brd]
2017-10-20 idea of an external cartridge
    [LAMEBOY.brd, LAMEBOY.sch]
2017-10-20 corrected rgb layout
    [LAMEBOY.brd, LAMEBOY.sch]
2017-10-20 moved sd slot slightley
    [LAMEBOY.brd]
2017-10-20 moved a via :D
    [LAMEBOY.brd]
2017-10-21 moved C and RST switch
    [LAMEBOY.brd, LAMEBOY.sch]
2017-10-21 usb logo
    [LAMEBOY.brd]
2017-10-23 wrong power for enabling regulator
    [LAMEBOY.brd, LAMEBOY.sch]
2017-10-25 layerstuff and footprints
    [LAMEBOY.brd, LAMEBOY.sch]
2018-01-09 hm, what happened here
    [LAMEBOY.brd, LAMEBOY.sch]
2018-01-24 moved 3.1 to 3.X
    added pull down power switch
    [LAMEBOY.brd, LAMEBOY.sch]
2018-02-20 minor changes to rev3.1
    [LAMEBOY.brd, LAMEBOY.sch]
2018-02-20 rev3.4 sound pins
    [LAMEBOY.brd, LAMEBOY.sch]
2018-02-20 external cartridge
    [LAMEBOY.brd, LAMEBOY.sch]
2018-02-20 case designs
2018-02-20 label for batteries
    [LAMEBOY.brd]
2018-02-20 moar labels
    [LAMEBOY.brd]
2018-02-21 moaar labels
    [LAMEBOY.brd]
2018-03-10 current version gerber
    [LAMEBOY.brd, LAMEBOY.sch]
2018-03-10 minor footprint changes
    [LAMEBOY.brd, LAMEBOY.sch]
2018-03-11 current bom
    [LAMEBOY_BOM.csv]
2019-08-22 sound and vibrator
    [LAMEBOY.brd, LAMEBOY.sch]
2019-08-30 bye c
    [LAMEBOY.brd]
2020-01-10 moved labels
    [LAMEBOY.brd]
2024-09-05 added KiCad Schematics of R3.2.1
    [LAMEBOY.brd, LAMEBOY.kicad_pcb, LAMEBOY.kicad_sch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]
2024-09-08 found the last version!
    [LAMEBOY.brd, LAMEBOY.kicad_pcb, LAMEBOY.kicad_sch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]

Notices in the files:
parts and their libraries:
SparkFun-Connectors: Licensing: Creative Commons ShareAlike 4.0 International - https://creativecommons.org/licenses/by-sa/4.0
